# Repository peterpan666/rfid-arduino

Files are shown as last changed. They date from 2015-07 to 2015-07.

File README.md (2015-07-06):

# rfid-arduino
Code Arduino du projet RFID
Projet réalisé dans le cadre du cours de RFID à Polytech' Montpellier
Contributeurs du projet Adrien Peyrouty, Bastien Boissin et Elie Faes

##Description
Le but du projet est de détecter la présence des étudiants en cours grace à des badges RFID.
Le système détecte le passage de l'étudiant par la porte et va ensuite envoyer un identifiant unique à un serveur web (voir [l'application web](https://github.com/peterpan666/rfid-webapp)) qui va horodater les informations et les afficher.

##Hardware
Les schéma, PCB et fichiers Gerber ont été générés avec le logiciel Diptrace

##Boitier
Tous les fichiers (.stl et .step) ont été générés avec le logiciel Solidworks

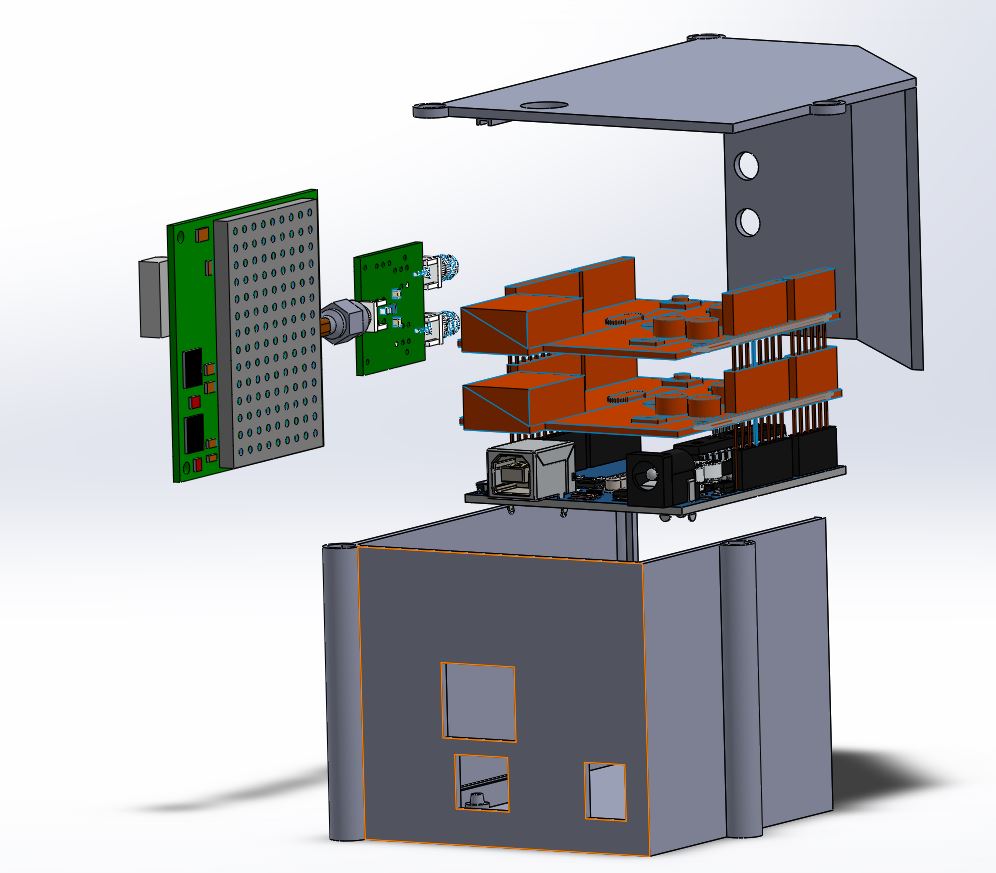
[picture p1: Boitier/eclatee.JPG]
vue éclatée


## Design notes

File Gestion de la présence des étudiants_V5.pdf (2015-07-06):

## Gestion de la présence des étudiants

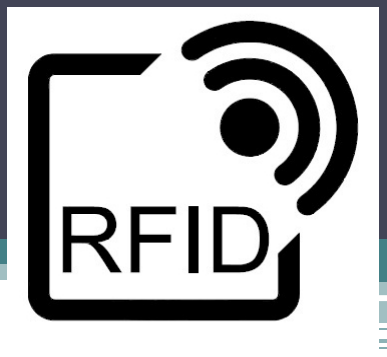
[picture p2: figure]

Cours de RFID (M. VENA, M. FOUCARAN)

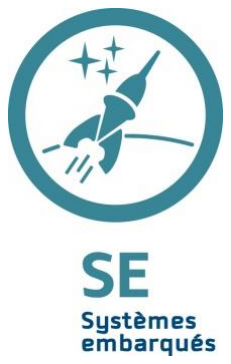
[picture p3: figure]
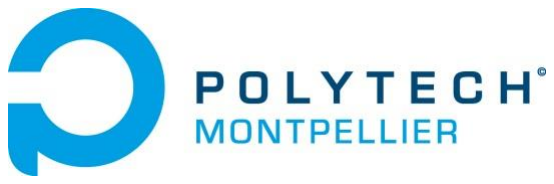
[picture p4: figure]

Adrien PEYROUTY
Elie FAES
Bastien BOISSIN

Lundi 6 Juillet 2015

## Sommaire

I. Présentation du projet
II. Gestion du projet
III. Réalisation
a. Lecteur UHF
b. Switch RF
c. OS temps-réel
d. Serveur web
e. Boitier imprimé en 3D
IV. Démonstration
Conclusion

## I. Présentation du projet

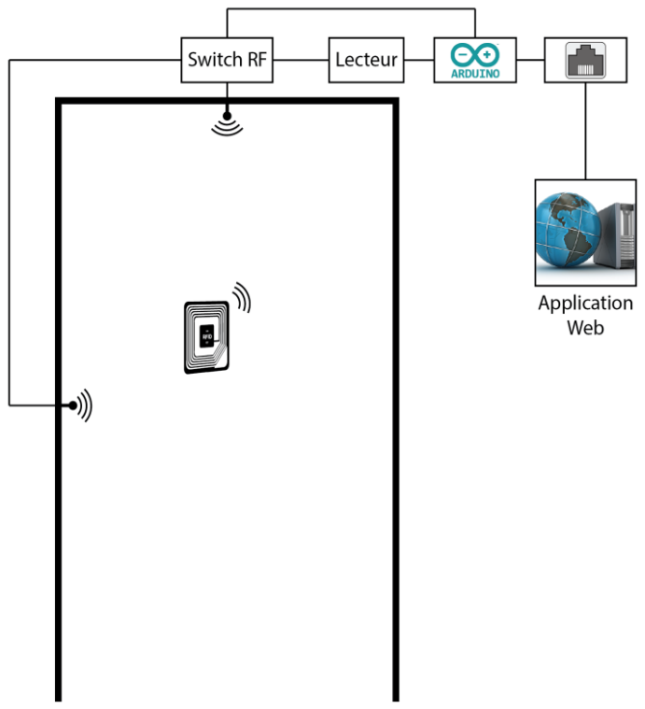
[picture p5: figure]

- Objectifs :
- Portique de détection RFID UHF
- Détection et enregistrement des passages
- Données collectées sur un serveur web
- Choix techniques :
- UHF → portée de détection
- OS temps réel → réactivité
- Schéma de principe :

## II. Gestion du projet

- Github.com
- Hébergement du code gratuit et illimité

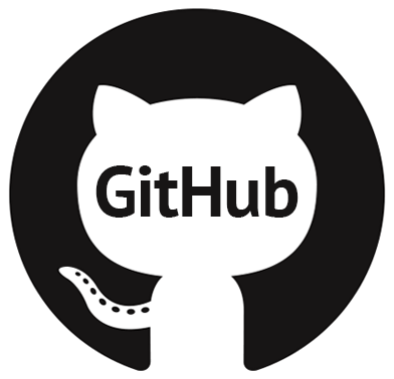
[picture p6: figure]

- Gestion des droits d’écriture/lecture simplifies

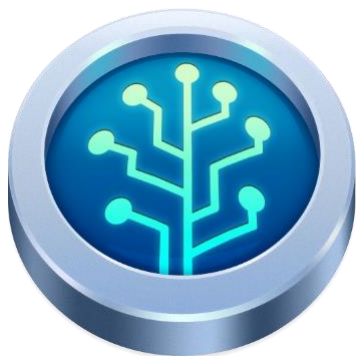
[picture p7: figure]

- Sourcetree
- Outil graphique de gestion de Git

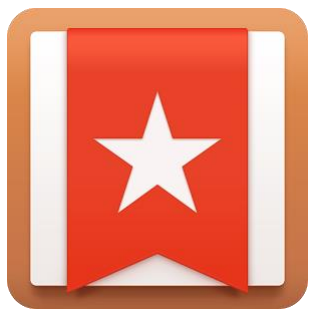
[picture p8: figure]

- Wunderlist
- TODO liste

## III. Réalisation

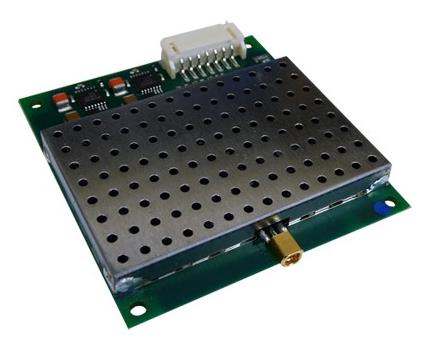
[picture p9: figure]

## III.a Lecteur UHF

- module StiD URI
- Alimentation 5V
- Puissance : 25dBm
- Communication UART (115200 bauds)
- Protocole : EPC1 Gen 2
- Port antenne monostatique
- Utilisé en mode « inventaire »

## III.a Lecteur UHF

- Communication
- Structure de la trame envoyé au lecteur
02 | 00 08 | 00 | 00 | 28 68
00 08 00 01 AA 55 | 00 00

## III.a Lecteur UHF

- Communication
- Structure de la trame envoyé par le lecteur

## III.b Switch RF

- Switch AS179-92LF
- Signaux de contrôle TTL
- Atténuation = 0,3dB
- Bande passante = 20MHz → 3GHz

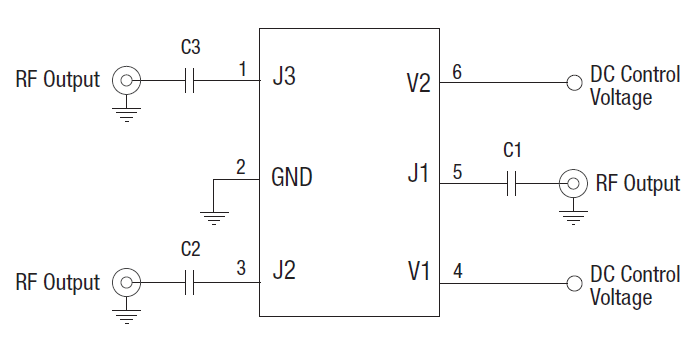
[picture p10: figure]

## III.b Switch RF

- Routage des pistes adaptées 50Ω
- Largeur des pistes = 1mm
- Isolation = 0,217mm

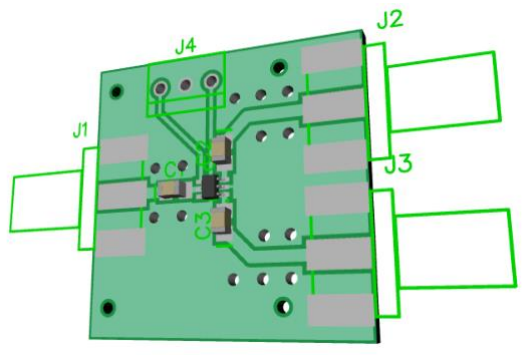
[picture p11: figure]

- Mesure des performances
- Atténuation sur la voie active = 0,9dB
- Atténuation sur la voie passive >20dB

## III.c OS temps-réel

OS_main() | Tâche_main()

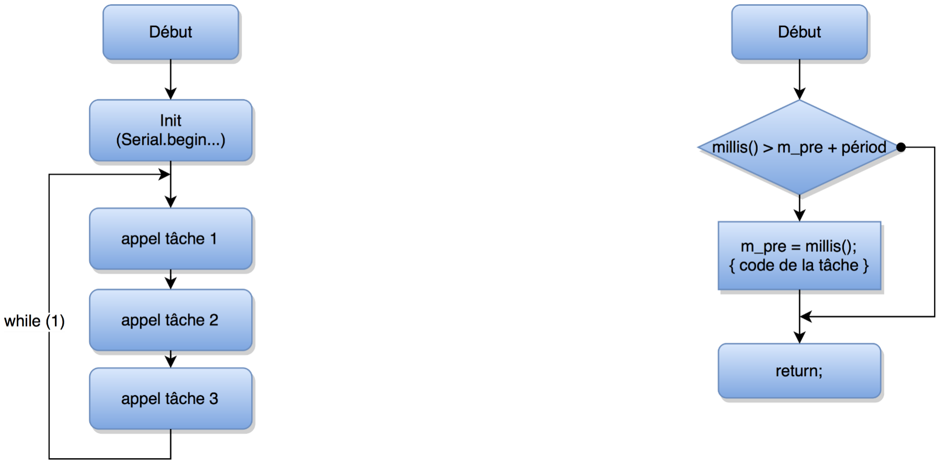
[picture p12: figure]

## III.c OS temps-réel : liste des tâches

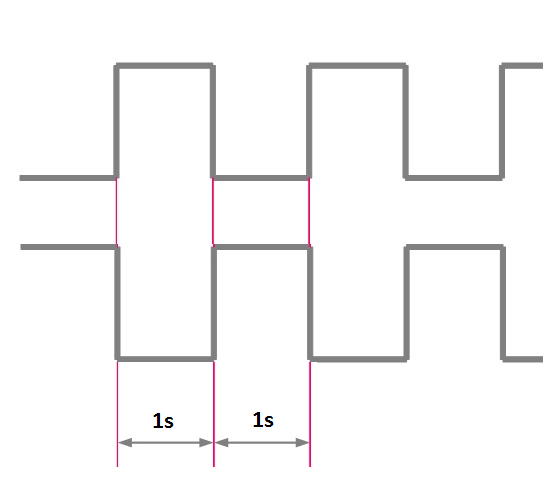
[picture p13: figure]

- Switch
- Periode : 1s
- Buzzer
- Variable et Blocante
- Read (vers lecteur)
- Période : 1s
- Write (réponse lecteur)
- Période 0,2s

## III.c OS temps-réel – Tâche Ethernet

- Shield Arduino Ethernet
- Protocole HTTP: méthode POST
- Mise en forme des données: JSON
- {“room”:”SE2”,”tag_id”:[“1234”,”5678”,”1234”]}

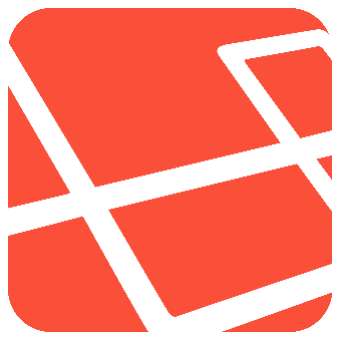
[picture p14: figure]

## III.d Serveur Web

- Framework PHP Laravel

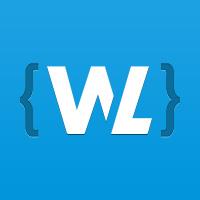
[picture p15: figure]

- Hébergement Weblogin

## III.e Boitier 3D

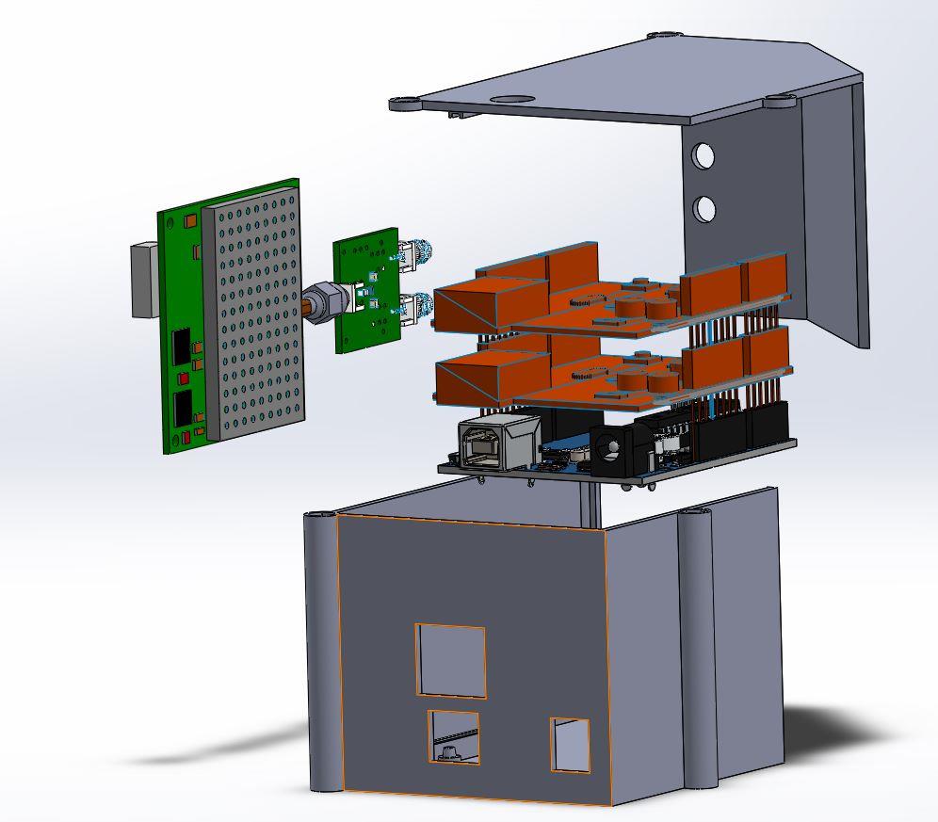
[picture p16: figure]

## V. Démonstration

## Conclusion

- Projet très formateur
- Mise en commun des compétences de l’équipe
- Utilisation concrète du RFID
- Regroupe les technologies clés de demain
- Sans fil (RFID)
- Objets connectés (connexion HTTP/serveur web)

## Merci pour votre attention

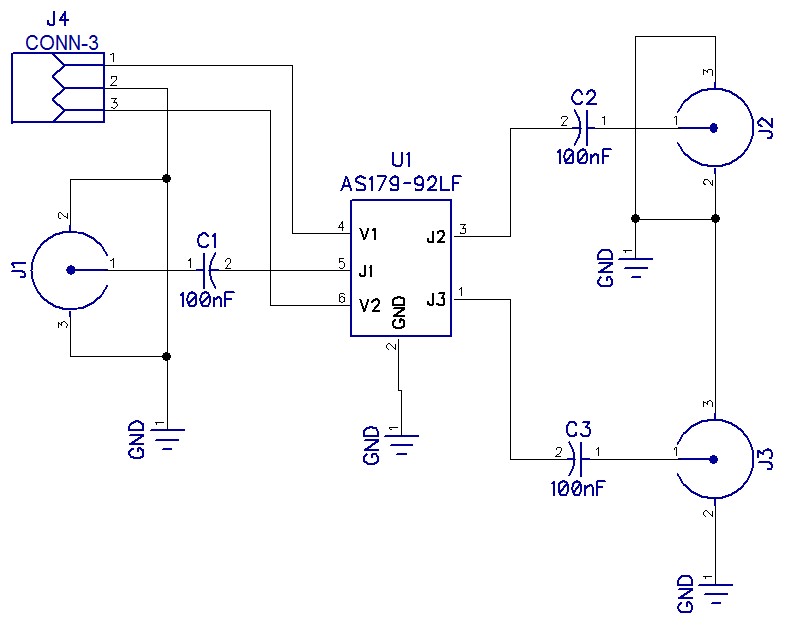
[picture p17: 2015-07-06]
Hardware/switch_schematic.jpg

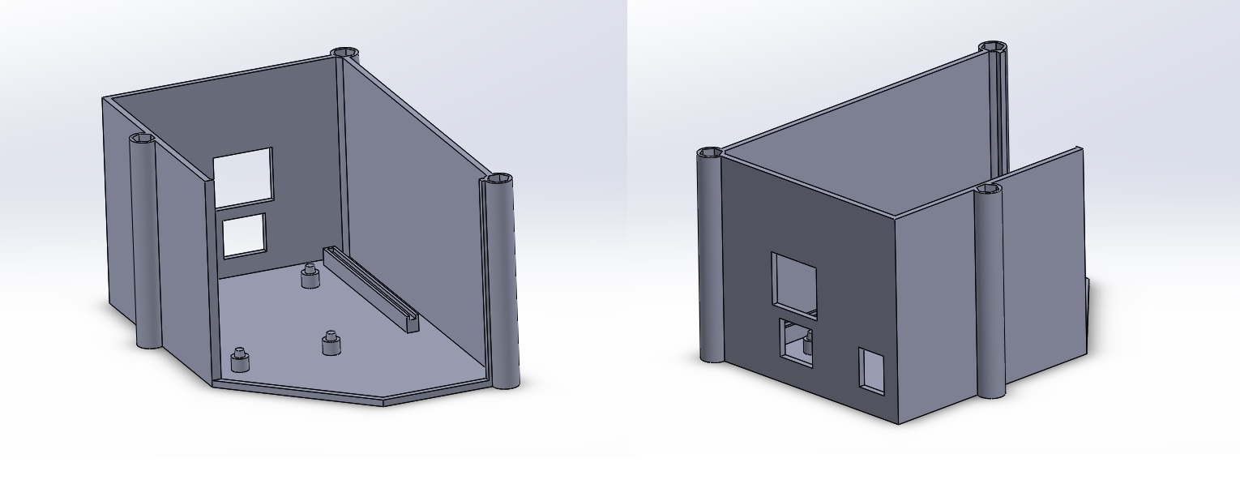
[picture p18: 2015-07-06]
Boitier/boitier_bottom.jpg

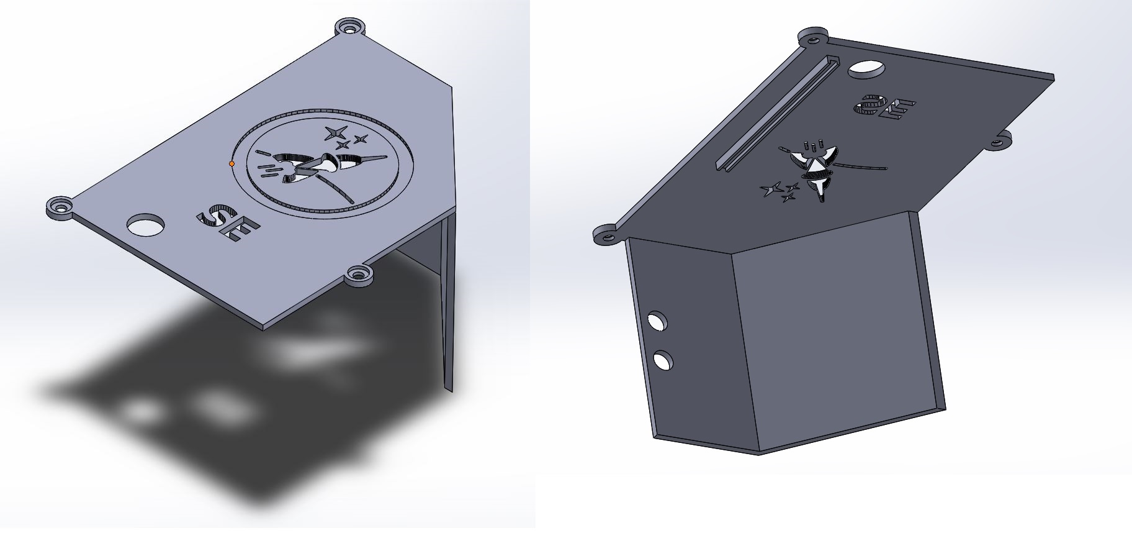
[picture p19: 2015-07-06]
Boitier/boitier_top.JPG

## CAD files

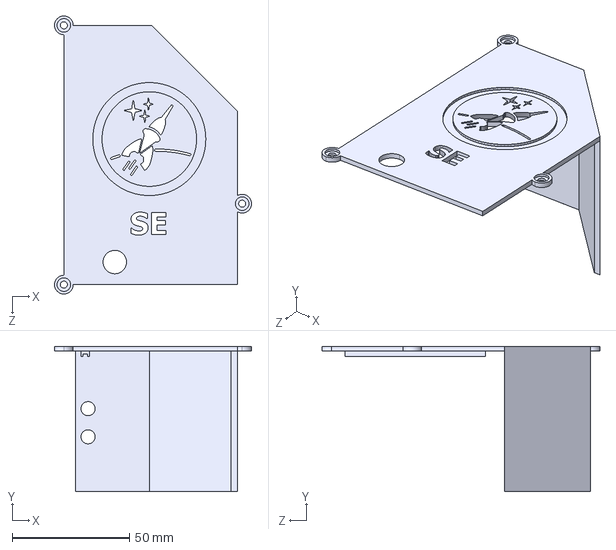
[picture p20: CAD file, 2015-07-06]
Boitier/boitier-top.STEP
84.0 x 62.0 x 118.5 mm

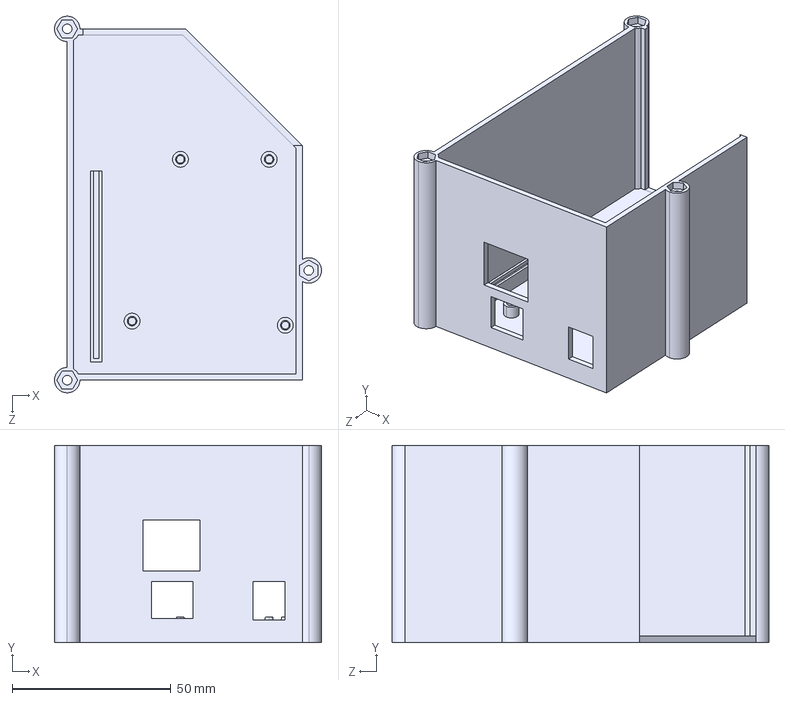
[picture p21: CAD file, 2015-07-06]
Boitier/boitier-bottom.STEP
84.0 x 62.0 x 118.5 mm

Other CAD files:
Boitier/boitier-bottom.STL
Boitier/boitier-top.STL

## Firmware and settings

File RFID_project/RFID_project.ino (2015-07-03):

/*
Projet de RFID
Polytech' Montpellier
Contributeurs: Adrien Peyrouty
              Bastien Boissin
              Elie Faes
*/
#include <SPI.h>
#include <Ethernet.h>


#define SW_V1 8
#define SW_V2 9
#define SW_PERIOD 1000
#define BUFFER_LENGHT  255

#define BIP_TASK_PERIOD 100
#define BIP_DURATION 100
#define BIP_IDLE   0
#define BIP_START  1
#define BIP_STOP   2
#define BUZZER_PIN 6

//#define MEGA
#define DEBUG false

#define debug_println(...)   if (DEBUG) Serial.println(__VA_ARGS__)
#define debug_print(...)     if (DEBUG) Serial.print(__VA_ARGS__)

unsigned long last_sw_task;
unsigned char v1 = HIGH, v2 = LOW;

unsigned char bip_state = BIP_IDLE;
unsigned long last_bip_task = 0;
unsigned long refresh_bip_task = BIP_TASK_PERIOD;

unsigned long last_write_task = 0;
unsigned long refresh_write_task = 200;
unsigned int tag_detected = 1;

unsigned long temp = 0;

unsigned long last_connection_task = 0;
unsigned long refresh_connection_task = 5000;

unsigned long last_reading_task = 0;
unsigned long refresh_reading_task = 1000;

// Sequence to send to the reader to make a complete inventory
byte inventory[] = { 0x02,0x00,0x08,0x00,0x00,0x00,0x08,0x00,0x01,0xAA,0x55,0x00,0x00,0x28,0x68 };

char send_buffer[32][12];

byte send_write = 0;
byte send_read = 0;
boolean Flag_request = false;
boolean Flag_response = true;
boolean Flag_bip = false;
String room = "SE2";

// Enter a MAC address for your controller below.
// Newer Ethernet shields have a MAC address printed on a sticker on the shield
byte mac[] = { 0xDE, 0xAD, 0xBE, 0xEF, 0xFE, 0xED };
// if you don't want to use DNS (and reduce your sketch size)
// use the numeric IP instead of the name for the server:
//IPAddress server(74,125,232,128);  // numeric IP for Google (no DNS)
char server[] = "elie.weblogin.fr";    // name address for Google (using DNS)

// Set the static IP address to use if the DHCP fails to assign
IPAddress ip(192,168,0,177);

// Initialize the Ethernet client library
// with the IP address and port of the server 
// that you want to connect to (port 80 is default for HTTP):
EthernetClient client;

boolean ethernet_init()
{
  debug_print("Ethernet init... ");
  if (Ethernet.begin(mac) == 0) {
    debug_println("Failed to configure Ethernet using DHCP");
    // no point in carrying on, so do nothing forevermore:
    // try to congifure using IP address instead of DHCP:
    //Ethernet.begin(mac, ip)
    //return true;
    return false;
  } else {
    debug_println("DHCP OK");
    return true;
  }
}

void init_connection_task() {
  while (!ethernet_init());
}

void htoa(char h[12], char s[24]) 
{
 char low, high;
 for (int i = 0; i < 12; i++) 
 {
    low = h[i] & 0x0f;
    high = (h[i] >> 4) & 0x0f;
    s[i*2 + 1] = low < 10 ? low + 48 : low + 65 - 10;
    s[i*2] = high < 10 ? high + 48 : high + 65 - 10;
 }
}

void main_connection_task(void)
{
    
    if (millis() < last_connection_task + refresh_connection_task) {
      return;
    }
    
    last_connection_task = millis();
    
    String data;
    char buffer[24] = {0};
    int i = 0;
    
    while (send_write != send_read) {
      
      data += "\"";
      htoa(send_buffer[send_read], buffer);
      
      for(unsigned int j=0; j<24; j++)
      {
        data += String(buffer[j]);
      }
      data += "\",";
      
      send_read++;
      if(send_read >= 31)
            send_read = 0;

      if (++i >= 10) {
        break;
      }
    }
    //debug_println(data);
    data = data.substring(0, data.length() - 1);
    
    if (data.length() == 0) {
      return;
    }
    
    String data_start = "{\"room\":\"" + room + "\",\"tag_id\":[";
    
    debug_println();
    debug_println(data);
    debug_println();
    
    debug_println("connecting...");
    
    if (client.connect(server, 80)) {
      debug_println("connected");
      debug_println("sending POST request");
      // Make a HTTP request:
      client.println("POST /classroom/store HTTP/1.0");
      client.print("Host: ");
      client.println(server);
      client.println("Content-type: application/json");
      client.println("Content-length: " + String(data_start.length() + data.length() + 2));
      client.println();
      client.print(data_start);
      client.print(data);
      client.print("]}");
      
      debug_println();
      debug_println("disconnecting.");
      client.stop();
    } 
    else {
      // kf you didn't get a connection to the server:
      debug_println("connection failed");
      return;
    }
}

void init_reading_task()
{
  debug_println("Initialisation reading");
  delay(500);
  Serial.flush(); 
}

void main_reading_task(void)
{
    if (millis() < last_reading_task + refresh_reading_task /*&& !Flag_response*/) 
    {
      return;
    }
    debug_print("start reading ...");
    last_reading_task = millis();
    #ifdef MEGA
      Serial1.write(inventory, sizeof(inventory)); //send the command to start new inventory
    #else
      Serial.write(inventory, sizeof(inventory)); //send the command to start new inventory
    #endif
    
    debug_println(" End reading"); 
    //Flag_request = true; 
    //Flag_response = false;
}

void my_memcpy(char* desti, char* source, int Nbyte, int offset)
{
  for(int i =0; i< Nbyte; i++)
  {
    desti[i] = source[i + offset];
  }  
}

void main_write_task(void)
{
    unsigned int i, NbTags = 0;
    char vide = 0;
    char header_buffer[BUFFER_LENGHT] = {0};
    char data_buffer[BUFFER_LENGHT] = {0};
    
    if (millis() < last_write_task + refresh_write_task /*&& !Flag_request*/) {
      return;
    }
    debug_print("start writing...");
    last_write_task = millis();
    
    #ifdef MEGA
      if(Serial1.available())
    #else defined UNO
      if(Serial.available())
    #endif
    {
      //Flag_response = true;
      #ifdef MEGA
        Serial1.readBytes(header_buffer, 9);
      #else defined UNO
        Serial.readBytes(header_buffer, 9);
      #endif  
      if(header_buffer[0] == 0x02 && header_buffer[6] == 0x01)
      {
        unsigned int Lin = header_buffer[7]*256 + header_buffer[8];
        debug_print("Lin = ");
        debug_println(Lin, DEC);
        for(unsigned int j=0; j<9; j++)
        {
          debug_print(header_buffer[j], HEX);
          debug_print(" ");
        }
        if(Lin < 17)
        {
         Flag_request = false;
         return;
        }
        #ifdef MEGA 
          Serial1.readBytes(data_buffer, Lin);
        #else defined UNO
          Serial.readBytes(data_buffer, Lin);
        #endif  
        
        NbTags = data_buffer[0];
        tag_detected += NbTags;
        debug_print("\n\r Nombre de tags = ");
        debug_println(NbTags);
        
        for(i=0; i<NbTags; i++)
        {
          my_memcpy(send_buffer[send_write++], data_buffer, 12, 2 + (16 * i));
          if(send_write >= 31)
            send_write = 0;
        }
      }
      #ifdef MEGA 
        while(Serial1.available())
        {
          Serial1.readBytes(&vide, 1);
        }
      #else
        while(Serial.available())
        {
          Serial.readBytes(&vide, 1);
        }
      #endif 
    } 
   debug_println(" end writing");
   //Flag_request = false;
}



void init_sw_task() {
  last_sw_task = 0;
  pinMode(SW_V1, OUTPUT);
  pinMode(SW_V2, OUTPUT);
  digitalWrite(SW_V1, v1);
  digitalWrite(SW_V2, v2);
}

void main_sw_task() {
  if (millis() < (last_sw_task + SW_PERIOD))
    return;
    
  last_sw_task = millis();
  v1 = v1 ? LOW : HIGH;
  v2 = v2 ? LOW : HIGH;
  digitalWrite(SW_V1, v1);
  digitalWrite(SW_V2, v2);
} 

void init_bip_task(){
  pinMode(BUZZER_PIN, OUTPUT);
}

void main_bip_task() {
  if (millis() < (last_bip_task + refresh_bip_task))
    return; 
  last_bip_task = millis();
  
  switch(bip_state){
    case BIP_IDLE :
      if (tag_detected > 0)
        bip_state = BIP_START;
      break;

    case BIP_START :
      if (tag_detected != 0) {
        Flag_bip = true;
        analogWrite(BUZZER_PIN, 800);
        refresh_bip_task = BIP_DURATION;
        bip_state = BIP_STOP;
      } else {
        bip_state = BIP_IDLE;
        refresh_bip_task = BIP_TASK_PERIOD;
      }
      break;
      
    case BIP_STOP :
      Flag_bip = false;
      analogWrite(BUZZER_PIN, 0);
      bip_state = BIP_START;
      refresh_bip_task = BIP_TASK_PERIOD;
      tag_detected--;
      break;
  }    
  return;
}

void setup() {
  Serial.begin(115200);
  #ifdef MEGA
    Serial1.begin(115200);
  #endif
  init_connection_task(); 
  init_sw_task();
  init_bip_task();
  init_reading_task();
  delay(1000);
  
}

void loop() {
  
  
  main_bip_task();
  main_sw_task();
  if(!Flag_bip)
  {
    main_connection_task();  
    main_reading_task();
    main_write_task();
  }
}

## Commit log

2015-06-24 Add switch control
2015-07-01 Buzzer with high priority
    [RFID_project.ino]
2015-07-03 Enable switch task with period of 1s. Adruino Uno target instead of Arduino Mega.
2015-07-06 Add box 3D model files
    [boitier-bottom.STEP, boitier-bottom.STL, boitier-top.STEP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]
2015-07-06 Add Powerpoint file
